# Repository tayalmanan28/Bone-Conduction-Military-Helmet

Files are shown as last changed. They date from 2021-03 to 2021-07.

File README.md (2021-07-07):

# Design of a Bone Conduction Military Helmet

## Course Project for ME 423 [Machine Design]

***

## Overview

Human Auditory nerve, which takes audio signals from cochlea to the brain, is connected to the Organ of Corti in cochlea which is located on the basilar membrane. Therefore the displacement at the basilar membrane directly affects the sound we hear. This basilar membrane can be stimulated in 2 ways:
● Air Conduction: Normal Hearing through eardrum vibrations transmitted via middle ear bones (malleus, incus, and stapes).
● Bone Conduction: Vibrations transmitted through the skull.
The way we hear our own voice even after closing our ears is through bone conduction. Bone conduction also occurs in our Normal Hearing state through the skull but the stimulation on the basilar membrane is extremely low below 100 dB. Above 100 dB we can hear the sound even if we close our ears using ear plugs which is due to bone conduction.

### Working Principle

In this report, bone conduction phenomenon is studied and a bone conduction helmet is designed. The major use of this helmet is for military purposes where the soldier needs to hear the surrounding noises as well as clearly hear the commands from his officer.

### [Project Report](https://github.com/tayalmanan28/Bone-Conduction-Military-Helmet/blob/main/Report.pdf)

### [Presentation](https://github.com/tayalmanan28/Bone-Conduction-Military-Helmet/blob/main/Presentation.pptx)

***

<p align='center'>Created with :heart: by  <a href="https://github.com/tayalmanan28">Manan Tayal</a>, <a> Atharv Kotwal </a>, <a> Milind Chandnani</a> & <a href="https://github.com/AmeyGohil">Amey Gohil</a></p>

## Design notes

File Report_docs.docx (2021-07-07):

Bone Conduction Military Helmet

ME791 Acoustic Devices Autumn 2020

Group:

- Atharv Kotwal (170110068)
- Manan Tayal (170100005)
- Amey Gohil (170100019)
- Milind Chandnani (170110001)

Introduction

Human Auditory nerve, which takes audio signals from cochlea to the brain, is connected to the Organ of Corti in cochlea which is located on the basilar membrane. Therefore the displacement at the basilar membrane directly affects the sound we hear. This basilar membrane can be stimulated in 2 ways:

- Air Conduction: Normal Hearing through eardrum vibrations transmitted via middle ear bones (malleus, incus, and stapes).
- Bone Conduction: is the conduction of sound to the inner ear primarily through the bones of the skull, allowing the hearer to perceive audio content without blocking the ear canal. Bone conduction transmission occurs constantly as sound waves vibrate bone, specifically the bones in the skull, although it is hard for the average individual to distinguish sound being conveyed through the bone as opposed to sound being conveyed through air via the ear canal.

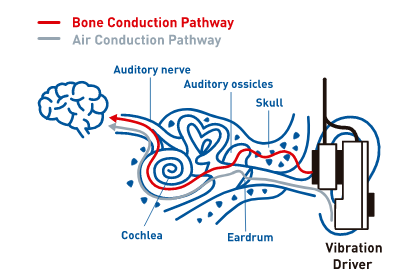
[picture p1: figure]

The way we hear our own voice even after closing our ears is through bone conduction. Bone conduction also occurs in our Normal Hearing state through the skull but the stimulation on the basilar membrane is extremely low below 100 dB. Above 100 dB we can hear the sound even if we close our ears using ear plugs which is due to bone conduction.

Bone conduction: An Overview

Bone conduction is one reason why a person's voice sounds different to them when it is recorded and played back. Because the skull conducts lower frequencies better than air, people perceive their own voices to be lower and fuller than others do, and a recording of one's own voice frequently sounds higher than one expects.

Musicians may use bone conduction using a tuning fork (https://en.wikipedia.org/wiki/Tuning_fork) while tuning stringed instruments. After the fork starts vibrating, placing it in the mouth with the stem between the back teeth ensures that one continues to hear the note via bone conduction, and both hands are free to do the tuning. Ludwig van Beethoven (https://en.wikipedia.org/wiki/Ludwig_van_Beethoven) was famously rumored to be using bone conduction after losing most of his hearing, by placing one end of a rod in his mouth and resting the other end on the rim of his piano.

Comparison of hearing sensitivity through bone conduction and directly through the ear canal can aid audiologists in identifying pathologies of the middle ear (https://en.wikipedia.org/wiki/Middle_ear)—the area between the tympanic membrane (https://en.wikipedia.org/wiki/Eardrum) (ear drum) and the cochlea (inner ear). If hearing is markedly better through bone conduction than through the ear canal (air-bone gap), problems with the ear canal (e.g. ear wax accumulation), the tympanic membrane or ossicles (https://en.wikipedia.org/wiki/Ossicles) can be suspected.

Our Design:

We are planning to design and analyse a military helmet embedded with bone conduction earphones which will be used to transfer the commands directly to the soldier instead of having an earphone which will cover the Soldier’s ear canal and might decrease the spatial awareness which might be critical in a warzone. Various problems will be solved using the design we are proposing and some of them are as below:

- The Soldiers in the war need to keep a walky talky in their hands in order to communicate with the control room and with each other. Also, if they wear a headphone over their ears they can only focus on talking and may miss the noise of some bullet/ bomb blast.
- So they need to talk to each other while knowing the war environment. And therefore they might want to use a bone conduction headphone with a mic to hear the sounds from the environment and at the same time talk to each other.
- Moreover since above 100 dB we can hear the sound even if we close our ears using ear plugs which is due to bone conduction, we can analyse the insulation through bone conduction.

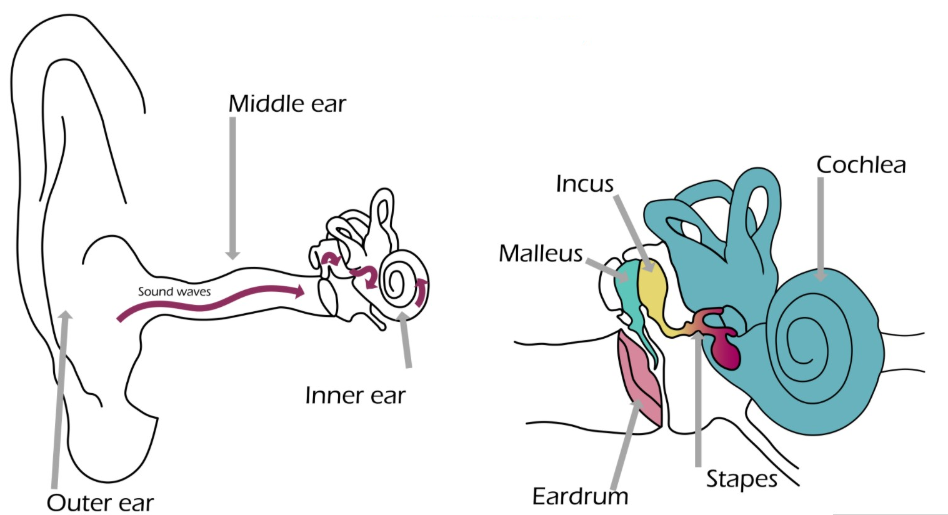
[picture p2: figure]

Working Principles

In this report, bone conduction phenomenon is studied and a bone conduction helmet is designed. The major use of this helmet is for military purposes where the soldier needs to hear the surrounding noises as well as clearly hear the commands from his officer.

The idea is to give commands using the bone conduction signal whereas the outside noises can be heard using normal air conduction hearing.

Modelling

Bone conduction happens through the skull, hence, ideally simulations should be performed on the whole skull. But to ease the complexity of the model, the skull was modelled as a sphere and some features like cochlear bones, ear canal and a flat surface to give vibrations were added. In the approximated skull 2 large holes are given to approximate many small openings in the skull. The images below show the approximated mesh as well as actual skull.

Cochlear Bones are highlighted in both. At the end of these bones a basilar membrane is presented.

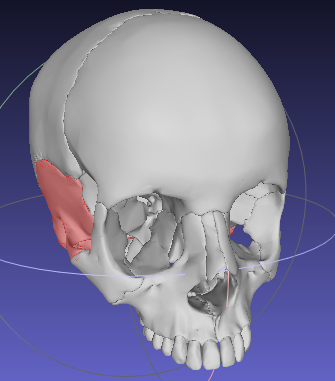
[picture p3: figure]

Actual Skull :

Material Properties of Bone:

Young’s Modulus E | 7300 MPa
Density | 870 kg/m³
Poisson Ratio | 0.3

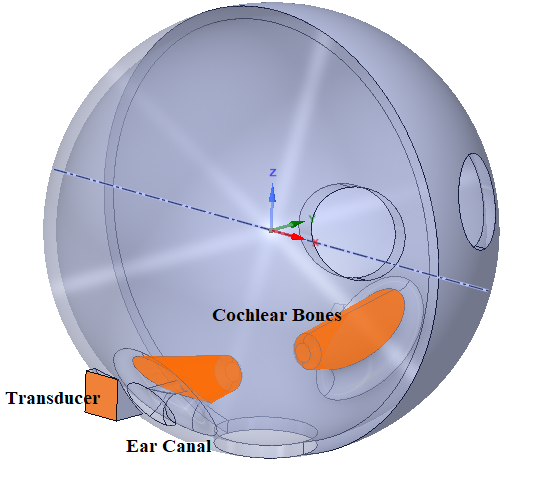
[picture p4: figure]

Approximated Model: Same material

Skull Thickness | 7.5 mm
Skull Diameter | 25 cm
Cochlear bone length | 7 cm
Cochlear bone diameter | 3 cm
Ear Canal Length | 3 cm
Ear Canal diameter | 8 mm
Transducer Area | 2.5 * 2.5 cm²

Model Validation

Model is validated by giving a point load of 1 N at one end (where the transducer is highlighted in Figure above). The mechanical impedance at the input was compared with the literature.

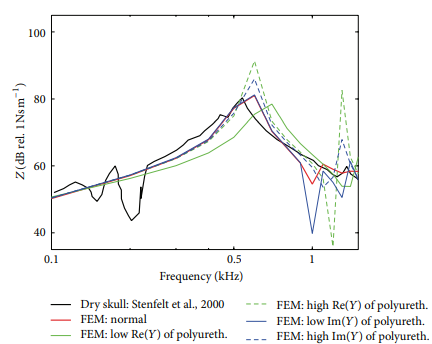
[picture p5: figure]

Literature:

Frequency Range: 100 - 1500 Hz

Model:

Frequency Range: 100 - 5000 Hz

- Trend is similar as given in literature.
- The peak occurs at 800 Hz compared to 600 Hz in literature.
- Mechanical Impedance of the model is higher than the actual skull given in literature because a uniform thickness sphere is considered everywhere which increases the stiffness whereas the actual skull has many openings and variation in thickness.

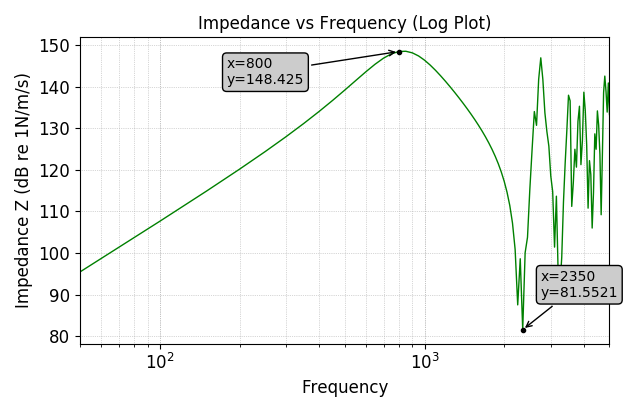
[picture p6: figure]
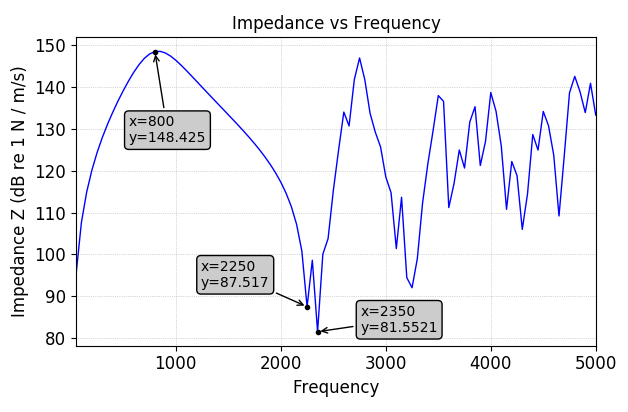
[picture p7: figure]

Frequency Range Selection

Now, a dynamic load is given over the whole area of transducer (2.5cm * 2.5cm) and Frequency Response is obtained for displacement at the end of cochlear bone.

Frequency Range: 50 - 5000 Hz

Load: 0.01 N

Transducer Area: 2.5 cm * 2.5 cm = 6.25 * 10 ⁻ ⁴ cm²

Pressure on Transducer: 16 Pa

Boundary Conditions:

- Fixed Support where skull connects the neck
- Specific Force on Transducer Area on both sides

Probe: Measure displacement at the end of cochlear bone which connects to basilar membrane

Software: Ansys Harmonic Response

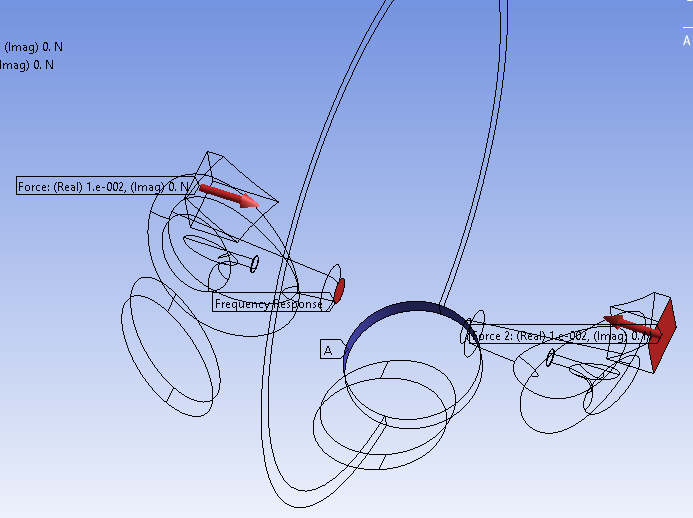
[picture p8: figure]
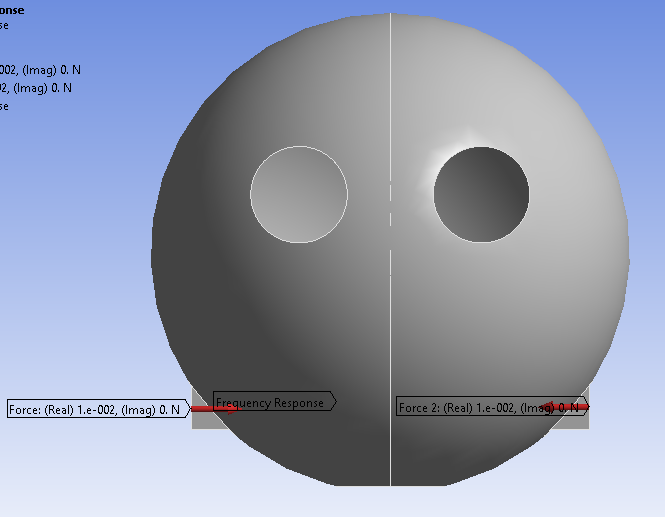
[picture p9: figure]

Results

Mechanical Impedance vs Frequency:

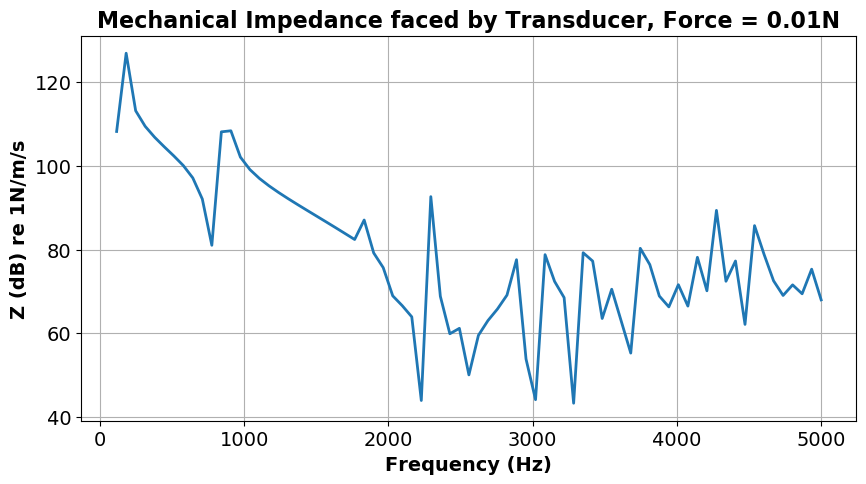
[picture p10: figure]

Frequency Response of Displacement at Basilar membrane:

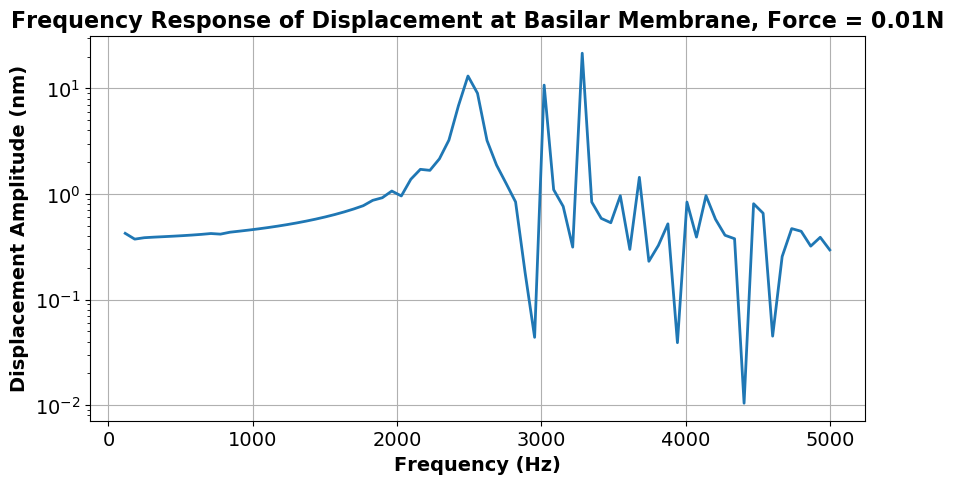
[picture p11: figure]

- The low frequency region ( <1500 Hz ) is not possible because of transducer limitations. Transducers of small sizes work best for higher frequencies.
- There is a peak at 2500 Hz where displacement is ~ 10 nm which is high for the basilar membrane. Also between 2300 - 3500 Hz, the region is highly non-linear with many peaks and troughs which is not good.
- Frequencies after 4000 Hz have smaller displacements.
- The best frequency range for our purpose is therefore 1800 - 2200 Hz i.e. we can tune the transducer around 2000 Hz Frequency.

Clamping Force Selection

The same model above is iterated a few times to get the best possible displacements at the basilar membrane.

Average displacement in frequency range 1800 - 2200 Hz:

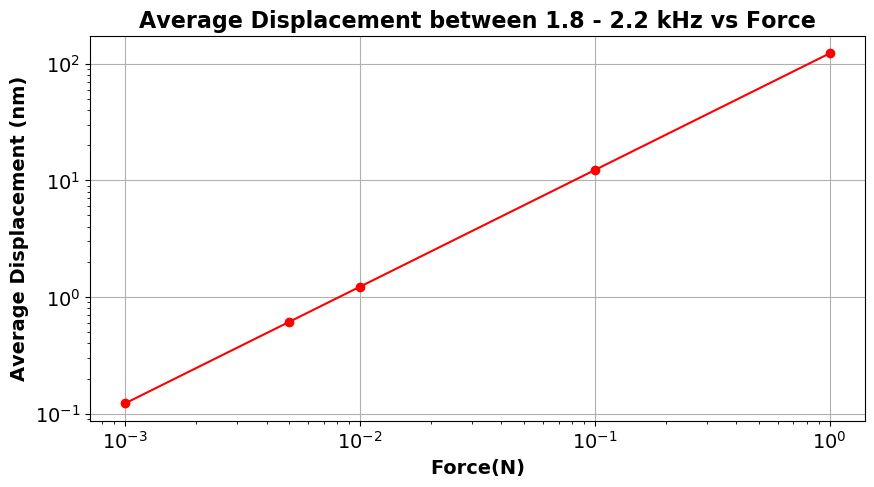
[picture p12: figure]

- Plot is fairly linear. Best Fit Equation:

log(disp in nm) = log(Force) + 2.089

- Displacement at the basilar membrane should be around 0.6 nm.
- Hence, the force amplitude to be applied on the skull should be ~ 0.005 N.
- Using the above equation force can be calculated for any displacement. Displacement at the basilar membrane for a particular frequency is directly proportional to the loudness of sound we hear.

Force amplitude on skull = 0.005 N

Pressure Amplitude ∆p = Force / Area = 0.005 / (2.5 * 2.5 cm² ) = 8 Pa

When a unit volt is passed through piezoelectric material it expands by ∆l

Therefore, εpiezo=∆l/l = d*E =d*V/l (where d is piezoelectric coefficient)

=2*10⁻¹² * (1/0.5*10⁻³)

=4*10⁻⁹

If we consider the skull bone to be stiff enough,

∆p/p =εpiezo / ε

= 4*10⁻⁹/1.6*10⁻⁶ (Allowable strain corresponding to the bearable stress)

=0.0025

In our case ∆p = 8 Pa

therefore, p = 8/0.0025Pa = 3200 Pa

Clamping Force = p * A = 3200 * (2.5 * 2.5 cm²) = 2 N.

Clamping Force can be slightly varied as per user requirement using the screw. Force on skull (= 0.0025 * Clamping Force ), which is a function of Clamping Force, governs the displacement of the membrane.

Effect of External Sound on Displacement at Cochlear End and Acoustic Insulation

A simple model of cochlear bone and external environment (Air domain) is created in Actran and displacements are calculated at cochlear end.

Air Domain | 30 cm * 30 cm * 30 cm
Cochlear bone length | 7 cm
Cochlear bone diameter | 3 cm

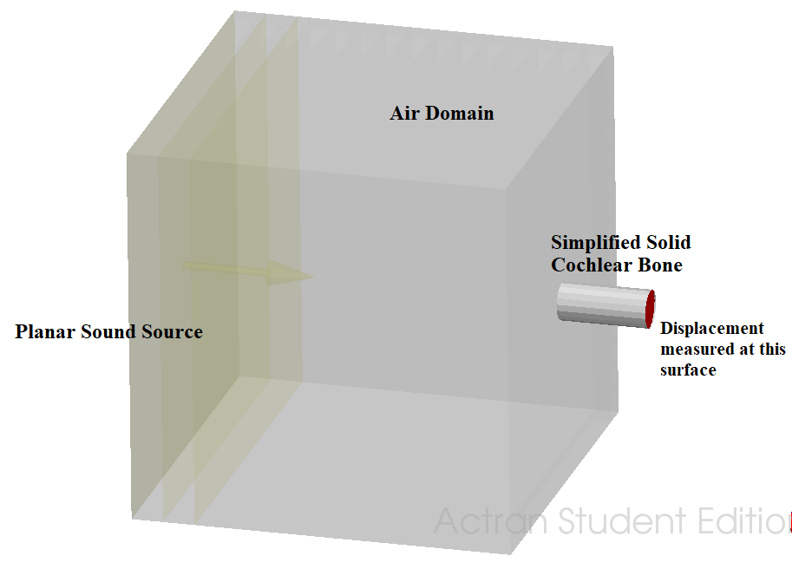
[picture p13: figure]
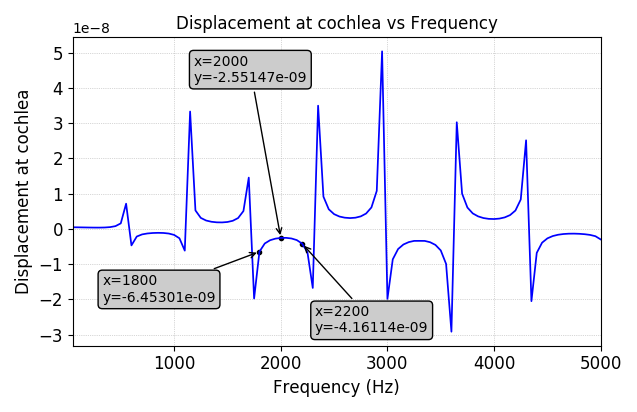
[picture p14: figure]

5 iterations were done with different pressure amplitudes.

Following graph shows displacement at cochlea for 100 Pa pressure Amplitude.

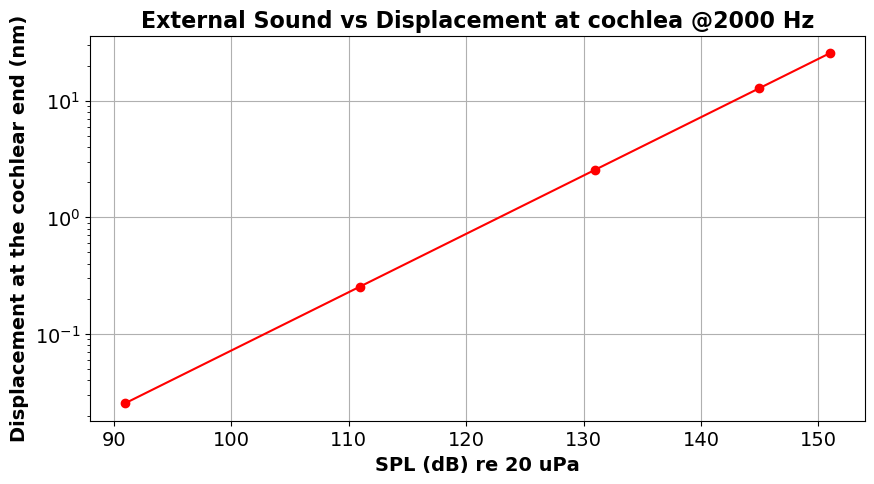
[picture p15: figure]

For 2000 Hz Frequency displacements are plotted against SPL (function of Pressure Amplitudes.)

- Plot is fairly linear.
- This clearly shows that above 100 dB, there is reasonable displacement due to bone conduction also on the basilar membrane of cochlea.
- This means that in a harsh acoustic environment (like navy aircraft carriers or sound of guns which goes upto 140 dB) with high noise levels even if the person wears ear plugs, he may end up damaging his basilar membrane because sound vibrations will travel through bone conduction.

Hence, a helmet is required which will attenuate these vibrations from entering the skull. Special materials like foam are inserted in the helmet for these purposes.

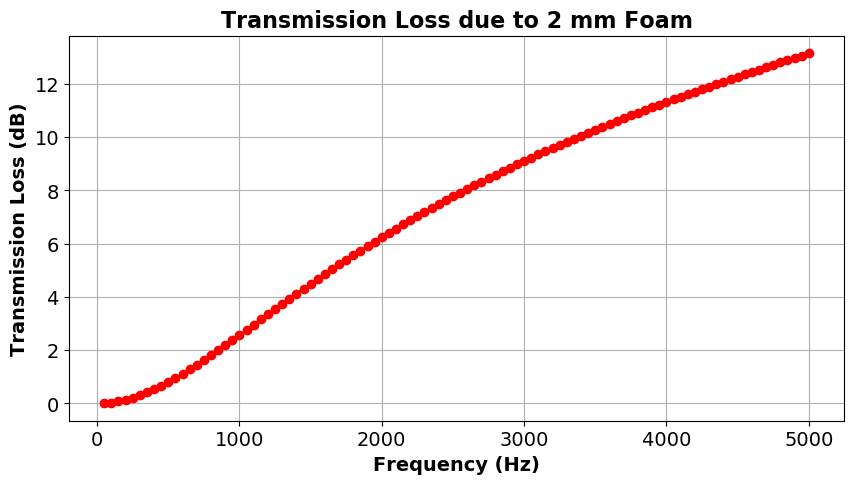
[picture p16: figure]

The bullets and bomb blasts generally create a noise at 1000Hz of frequency.

Sound to attenuate = 40 dB

Therefore, we need at least (40 / 2.5)*2mm = 32mm of foam to attenuate this noise.

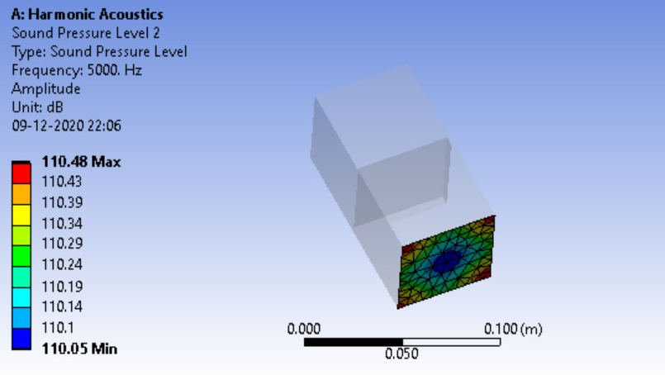
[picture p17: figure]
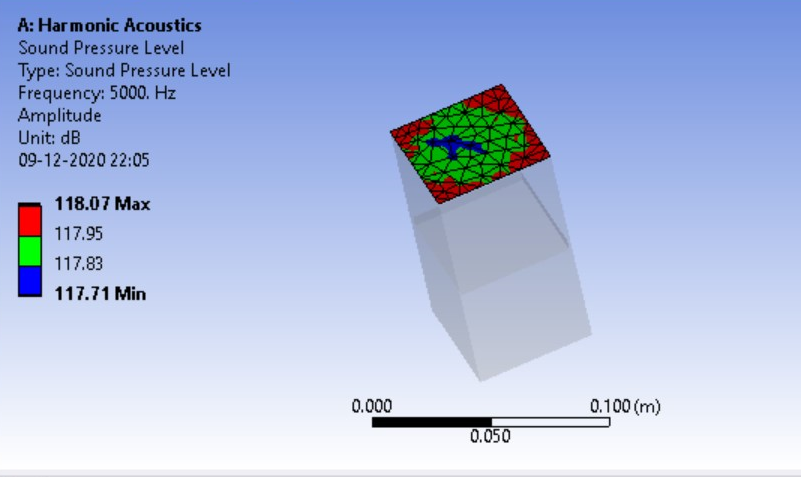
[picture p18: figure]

Electronics Circuit

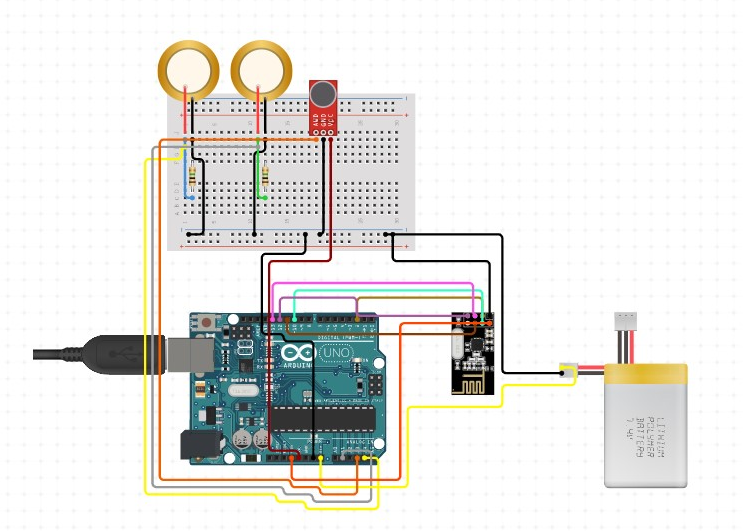
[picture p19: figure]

The electronics part contains Arduino (microcontroller), NRF24L01 - 2.4G Wireless Transceiver Module to receive and transmit the signals back and forth to the soldier, Piezo Transducer to conduct the signals from circuit to the cochlea via bone, Lithium Polymer Battery to power up the circuit and the microphone to communicate.

Material Analysis

Firstly we will analyse the impact analysis (if the thickness of a certain material can prevent the bullet from piercing the material).

Considering the following conditions we obtain the table below:

Bullet: Lead 20 mm Factor of Safety = 2 Velocity of the Bullet: 500 m/s

Plate Material | Thickness | Remarks | Thickness with FOS | Mass (kg)
Steel | 0.5 mm | Failed | 1mm | 0.8
Kevlar | 0.5 mm | Failed | 1mm | 0.144
UHMWP | 0.5 mm | Failed | 1mm | 0.097
Steel | 3 mm | Passed | 6mm | 4.8
Kevlar | 3 mm | Passed | 6mm | 0.864
UHMWP | 3 mm | Failed | 6mm | 0.582
UHMWP | 4 mm | Failed | 8mm | 0.776
UHMWP | 8 mm | Passed | 16mm | 1.552

Following are the gifs of the impact on the flat plate

Kevlar 3mm UHMWP 3mm

UHMWP 4mm UHMWP 8mm

Manufacturing drawings

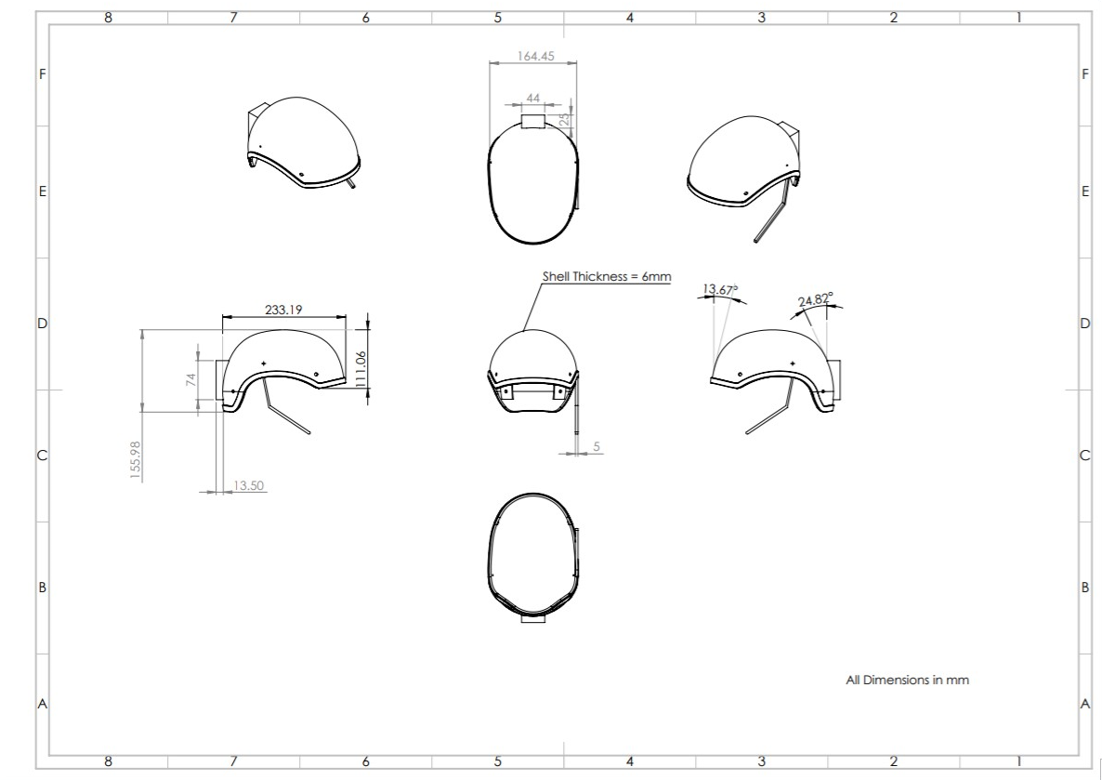
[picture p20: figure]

CAD Models

Helmet

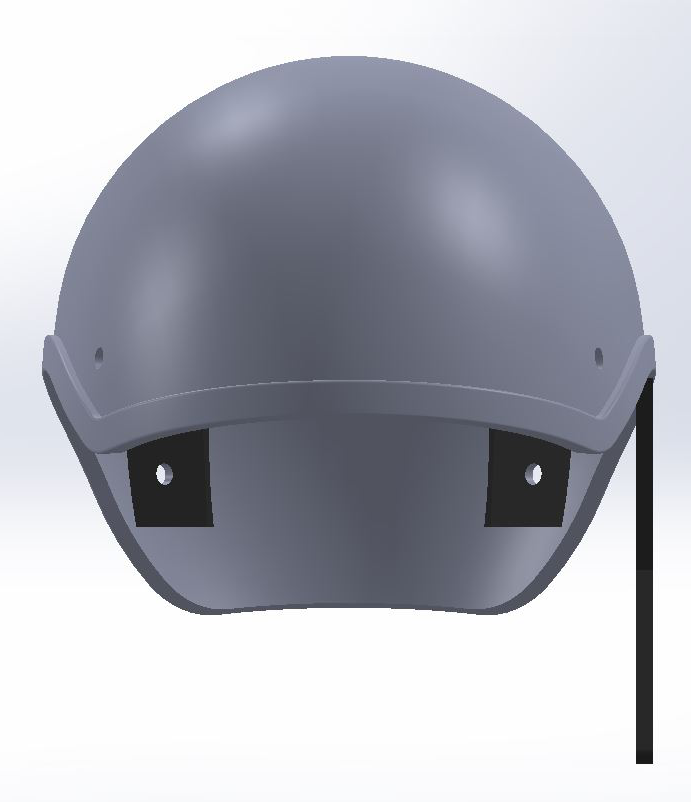
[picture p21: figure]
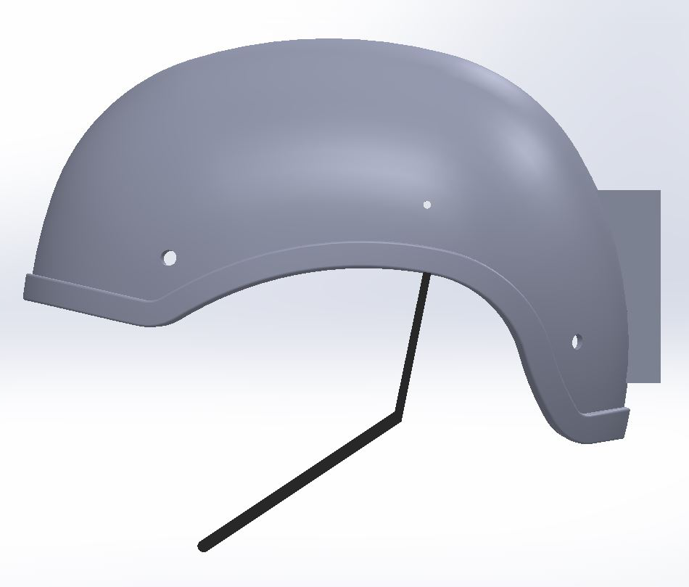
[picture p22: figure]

A basic helmet model is made using SolidWorks. It has a box compartment to store the electrical circuit on the back side. For placing the transducer, there are two slots on the inner surface at the back of the helmet. A metal strip is added on the side to account for the mike for communication purposes.

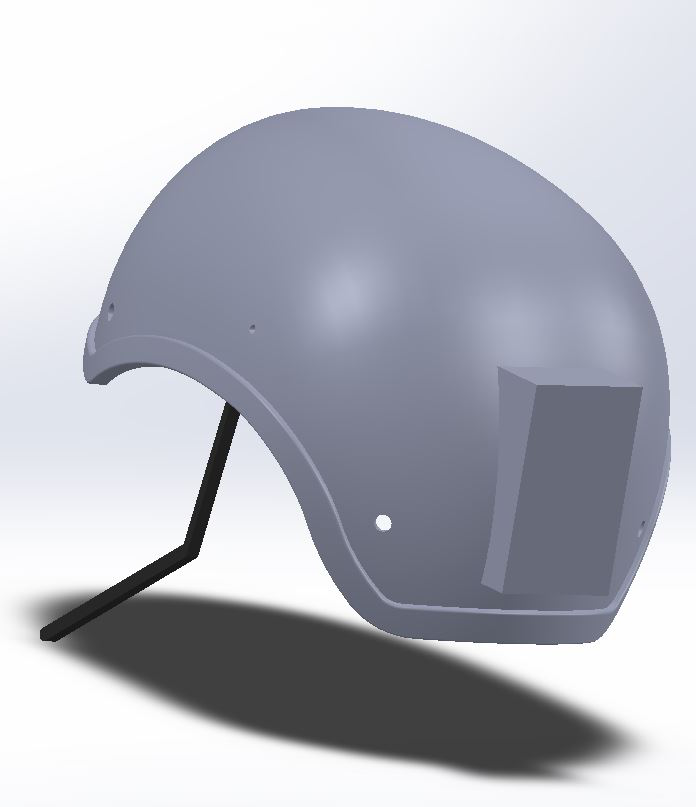
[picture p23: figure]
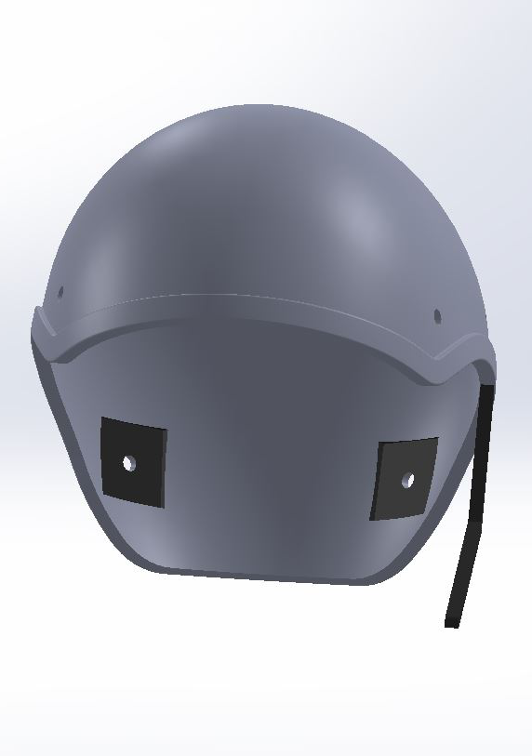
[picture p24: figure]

Spring Plunger

A spring plunger is also added to make fine adjustments

For Fine tuning of contact force mentioned above, We want 0.02N change in one pitch (pitch 1.25mm)

Stiffness of spring is 0.02N/1.25mm = 16N/m.

Bill of the components

Name of component | Quantity | Price (in INR)
Arduino | 1 | 500
NRF24L01 - 2.4G Wireless Transceiver Module | 1 | 100
Piezo Transducer | 2 | 60
1.0M Ohm Resistor | 2 | 2
Lithium Polymer Battery - 7.4v | 1 | 1000
Microphone | 1 | 250
Wires | | 50
Perforated Board | 2 | 80
Kevlar | 1kg | 600
Foam | | 1000
Spring Plunger | 2 | 200
Miscellaneous | | 500
Total | | 4042

Final Design Specifications

Helmet Thickness - 6mm Helmet Mass Volume - 582.93cm³

Material - Kevlar Mass of Helmet - 864 gm

Spring Plunger pitch - 1.25mm

Stiffness = 16N/m

Transducer Area - 2.5 cm * 2.5 cm³

Clamping Force - 2N

Frequency Range - 1800 - 2200 Hz

Summary and Highlights of the project

Final Product is a Helmet for Military Purposes with these features:

- Bone Conduction transmission of sound for clear hearing of commands
- Acoustically Insulating Foam for high noise levels.
- Other features of helmet like bullet proofing etc.

The main aim of the project was to incorporate bone conduction transmission in helmets and to prevent the external large sounds to enter the head and thereby the cochlea along with the traditional use to protect the head from bullets.

Contribution from each member

Atharv Kotwal | 25% | Acoustic Analysis: Frequency and Clamping Force Selection
Manan Tayal | 25% | Electronic Circuit and Acoustic Insulation
Amey Gohil | 25% | CAD Modelling
Milind Chandnani | 25% | Material Selection using Ansys Impact Analysis and Simulations

Link of all the Ansys, Actran & CAD Models along with a few videos is here (https://drive.google.com/drive/folders/1KnRmxevO2PZcEWRhP4DjEP5oWg9iEjO7?usp=sharing)

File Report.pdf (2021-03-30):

/

## Bone Conduction Military Helmet

### ME423 Machine Design Autumn 2020 Group 8

- Atharv Kotwal (170110068)
- Manan Tayal (170100005)
- Amey Gohil (170100019)
- Milind Chandnani (170110001)
- Bavish K (170040106)

Human Auditory nerve, which takes audio signals from cochlea to the brain, is connected to the Organ of Corti in cochlea which is located on the basilar membrane. Therefore the displacement at the basilar membrane directly affects the sound we hear. This basilar membrane can be stimulated in 2 ways:
- Air Conduction: Normal Hearing through eardrum vibrations transmitted via middle ear bones (malleus, incus, and stapes).
- Bone Conduction: Vibrations transmitted through the skull.
The way we hear our own voice even after closing our ears is through bone conduction. Bone conduction also occurs in our Normal Hearing state through the skull but the stimulation on the basilar membrane is extremely low below 100 dB. Above 100 dB we can hear the sound even if we close our ears using ear plugs which is due to bone conduction.

Need
- The Soldiers in the war need to keep a walky talky in their hands in order to communicate with the control room and with each other. Also, if they wear a headphone over their ears they can only focus on talking and may miss the noise of some bullet/ bomb blast.
- So they need to talk to each other while knowing the war environment. And
| therefore they might want to use a bone conduction headphone with a mic to
| hear the sounds from the environment and at the same time talk to each other.
- Moreover since above 100 dB we can hear the sound even if we close our ears using ear plugs which is due to bone conduction, we can analyse the insulation through bone conduction.

Working Principles
In this report, bone
conduction phenomenon is
studied | and | a | bone
conduction | helmet | is
designed. The major use of this helmet is for military purposes where the soldier
needs | to | hear | the
surrounding noises as well
as | clearly | hear | the
commands from his officer.


The idea is to give commands using the bone conduction signal whereas the outside noises can be heard using normal air conduction hearing.

### Modelling

Bone conduction happens through the skull, hence, ideally simulations should be performed on the whole skull. But to ease the complexity of the model, the skull was modelled as a sphere and some features like cochlear bones, ear canal and a flat surface to give vibrations were added. In the approximated skull 2 large holes are given to approximate many small openings in the skull. The images below show the approximated mesh as well as actual skull.
Cochlear Bones are highlighted in both. At the end of these bones a basilar membrane is presented.

Actual Skull :

Material Properties of Bone:


Approximated Model: Same material

Young’s Modulus E | 7300 MPa
Density | 870 kg/m³
Poisson Ratio | 0.3
Skull Thickness | 7.5 mm
Skull Diameter | 25 cm
Cochlear bone length | 7 cm
Cochlear bone diameter | 4 cm
Ear Canal Length | 3 cm
Ear Canal diameter | 8 mm
Transducer Area | 2.5 * 2.5 cm²

### Model Validation


Model is validated by giving a point load of 1 N at one end (where the transducer is highlighted in Figure above). The mechanical impedance at the input was compared with the literature.

Literature:
Frequency Range: 100 - 1500 Hz

Model:
Frequency Range: 100 - 5000 Hz
- Trend is similar as given in literature.
- The peak occurs at 800 Hz
compared to 600 Hz in
literature.
- Mechanical Impedance of the model is higher than the actual skull given in literature because a uniform thickness sphere is considered everywhere which increases the stiffness whereas the actual skull has many openings and variation in thickness.

### Frequency Range Selection

Now, a dynamic load is given over the whole area of transducer (2.5cm * 2.5cm) and Frequency Response is obtained for displacement at the end of cochlear bone.

Frequency Range: 50 - 5000 Hz
Load: 0.01 N
Transducer Area: 2.5 cm * 2.5 cm = 6.25 * 10
- 4 cm²
Pressure on Transducer: 16 Pa

Boundary Conditions:
- Fixed Support where skull connects the neck
- Specific Force on Transducer Area on both sides

Probe: Measure displacement at the end of cochlear bone which connects to basilar membrane
Software: Ansys Harmonic Response


Results
Mechanical Impedance vs Frequency:


Frequency Response of Displacement at Basilar membrane:


- The low frequency region ( <1500 Hz ) is not possible because of transducer limitations. Transducers of small sizes work best for higher frequencies.
- There is a peak at 2500 Hz where displacement is ~ 10 nm which is high for the basilar membrane. Also between 2300 - 3500 Hz, the region is highly non-linear with many peaks and troughs which is not good.
- Frequencies after 4000 Hz have smaller displacements.
- The best frequency range for our purpose is therefore 1800 - 2200 Hz i.e. we can tune the transducer around 2000 Hz Frequency.

### Clamping Force Selection

The same model above is iterated a few times to get the best possible displacements at the basilar membrane.
Average displacement in frequency range 1800 - 2200 Hz:


- Plot is fairly linear. Best Fit Equation:
log(disp in nm) = log(Force) + 2.089
- Displacement at the basilar membrane should be around 0.6 nm.
- Hence, the force amplitude to be applied on the skull should be ~ 0.005 N.
- Using the above equation force can be calculated for any displacement. Displacement at the basilar membrane for a particular frequency is directly proportional to the loudness of sound we hear.

Force amplitude on skull = 0.005 N
Pressure Amplitude ∆p = Force / Area = 0.005 / (2.5 * 2.5 cm²
) = 8 Pa

When a unit volt is passed
through piezoelectric material it
expands by ∆l
Therefore, εpiezo=∆l/l
= d*E =d*V/l | (where
d is piezoelectric coefficient)


=2*10 | -12 * (1/0.5*10

-3
)
=4*10

-9

If we consider the skull bone to be stiff enough, ∆p/p =εpiezo

/ ε
= 4*10

-9
/1.6*10

-6
(Allowable strain corresponding to the bearable stress) =0.0025
In our case ∆p = 8 Pa
therefore, p = 8/0.0025Pa = 3200 Pa
Clamping Force = p * A = 3200 * (2.5 * 2.5 cm²
) = 2 N.

Clamping Force can be slightly varied as per user requirement using the screw. Force on skull (= 0.0025 * Clamping Force ), which is a function of Clamping Force, governs the displacement of the membrane.

Acoustic Insulation in Helmet:
Using the force applied through the transducer, equivalent Sound Pressure Level can be calculated using the following:
SPL(dB) = 20 * log ( P / Pref ) , where, Pref = 20 * 10

-6 Pa
P = F / A , A = 2.5 * 2.5 cm²


- This plot shows that if the external sound is above 100 dB, then it can be perceived by cochlea through bone conduction.
- This means that in a harsh acoustic environment (like navy aircraft carriers or sound of guns which goes upto 140 dB) with high noise levels even if the person wears ear plugs, he may end up damaging his basilar membrane because sound vibrations will travel through bone conduction.

- Hence, a helmet is required which will attenuate these vibrations from entering the skull. Special materials like foam are inserted in the helmet for these purposes.


The bullets and bomb blasts generally create a noise at 1000Hz of frequency. Sound to attenuate = 40 dB
Therefore, we need at least (40 / 2.5)*2mm = 32mm of foam to attenuate this noise.


Electronics Circuit


The electronics part contains Arduino (microcontroller), NRF24L01 - 2.4G Wireless Transceiver Module to receive and transmit the signals back and forth to the soldier, Piezo Transducer to conduct the signals from circuit to the cochlea via bone, Lithium Polymer Battery to power up the circuit and the microphone to communicate.

Material Analysis
Firstly we will analyse the impact analysis (if the thickness of a certain material can prevent the bullet from piercing the material).
Considering the following conditions we obtain the table below:
Bullet: Lead 20 mm | Factor of Safety = 2 | Velocity of the Bullet: 500 m/s

Following are the gifs of the impact on the flat plate


Kevlar 3mm | UHMWP 3mm


UHMWP 4mm | UHMWP 8mm
Plate Material | Thickness | Remarks | Thickness with FOS | Mass (kg)
Steel | 0.5 mm | Failed | 1mm | 0.8
Kevlar | 0.5 mm | Failed | 1mm | 0.144
UHMWP | 0.5 mm | Failed | 1mm | 0.097
Steel | 3 mm | Passed | 6mm | 4.8
Kevlar | 3 mm | Passed | 6mm | 0.864
UHMWP | 3 mm | Failed | 6mm | 0.582
UHMWP | 4 mm | Failed | 8mm | 0.776
UHMWP | 8 mm | Passed | 16mm | 1.552


Next we need to analyse the impact energy of the cases in which the bullet is not penetrating:

Kevlar 3mm Plate

Max impact (internal) energy is around 3900J
Therefore, impact strength is impact (internal) energy/ thickness= 3900/3 J/mm = 1.3 MJ/m
UHMWP 8mm Plate

Max impact (internal) energy is around 4100J
Therefore, impact strength is impact (internal) energy/ thickness = 4100/8 J/mm = 0.512 MJ/m


Manufacturing drawings

CAD Models

Helmet

A basic helmet model is made using SolidWorks. It has a box compartment to store the electrical circuit on the back side. For placing the transducer, there are two slots on the inner surface at the back of the helmet. A metal strip is added on the side to account for the mike for communication purposes.

Spring Plunger

A spring plunger is also added to make fine adjustments
For Fine tuning of contact force mentioned above, We want 0.02N change in one pitch (pitch 1.25mm)
Stiffness of spring is 0.02N/1.25mm = 16N/m.

Bill of the components


Name of component | Quantity | Price (in INR)
Arduino | 1 | 500
NRF24L01 - 2.4G Wireless Transceiver Module | 1 | 100
Piezo Transducer | 2 | 60
1.0M Ohm Resistor | 2 | 2
Lithium Polymer Battery - 7.4v | 1 | 1000
Microphone | 1 | 250
Wires | | 50
Perforated Board | 2 | 80
Kevlar | 1kg | 600
Foam | | 1000
Spring Plunger | 2 | 200
Miscellaneous | | 500
Total | | 4042

Final Design Specifications
Helmet Thickness - 6mm | Helmet Mass Volume - 582.93cm³
Material - Kevlar | Mass of Helmet - 864 gm
Spring Plunger pitch - 1.25mm
Stiffness = 16N/m
Transducer Area - 2.5 cm * 2.5 cm³
Clamping Force - 2N
Frequency Range - 1800 - 2200 Hz

### Summary and Highlights of the project

Final Product is a Helmet for Military Purposes with these features:

- Bone Conduction transmission of sound for clear hearing of commands
- Acoustically Insulating Foam for high noise levels.
- Other features of helmet like bullet proofing etc.

The main aim of the project was to incorporate bone conduction transmission in helmets and to prevent the external large sounds to enter the head and thereby the cochlea along with the traditional use to protect the head from bullets.

Contribution from each member

Atharv Kotwal | 20% | Acoustic Analysis: Frequency and Clamping Force Selection
Manan Tayal | 20% | Electronic Circuit and Acoustic Insulation
Amey Gohil | 20% | CAD Modelling
Milind Chandnani | 20% | Material Selection using Ansys Impact Analysis and Simulations
Bavish K | 20% | CAD Modelling , Acoustic Model Approximation

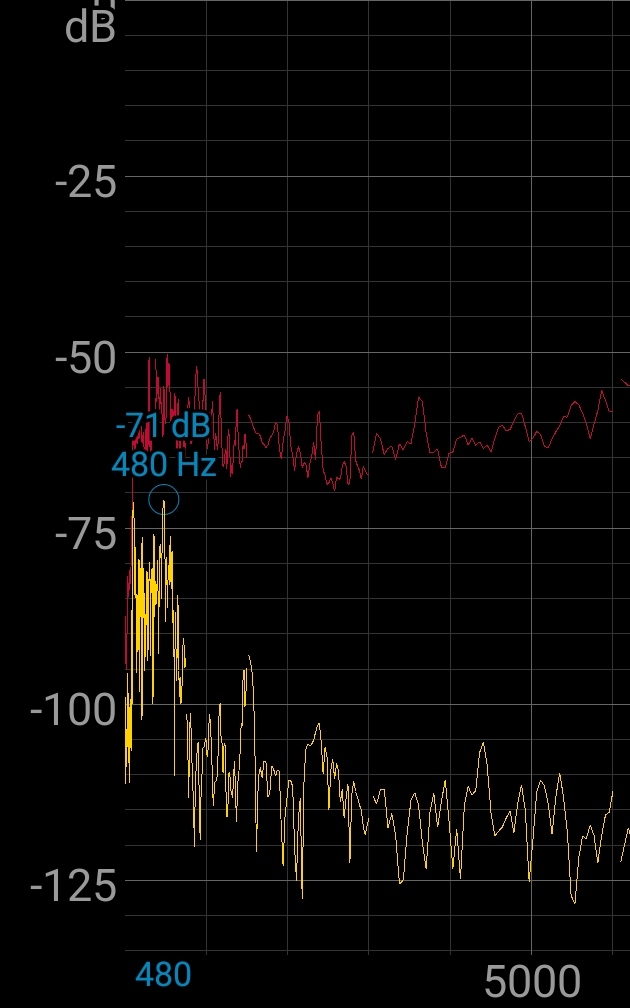
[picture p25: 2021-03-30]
Electrical Simulation/Piezo_off.jpeg

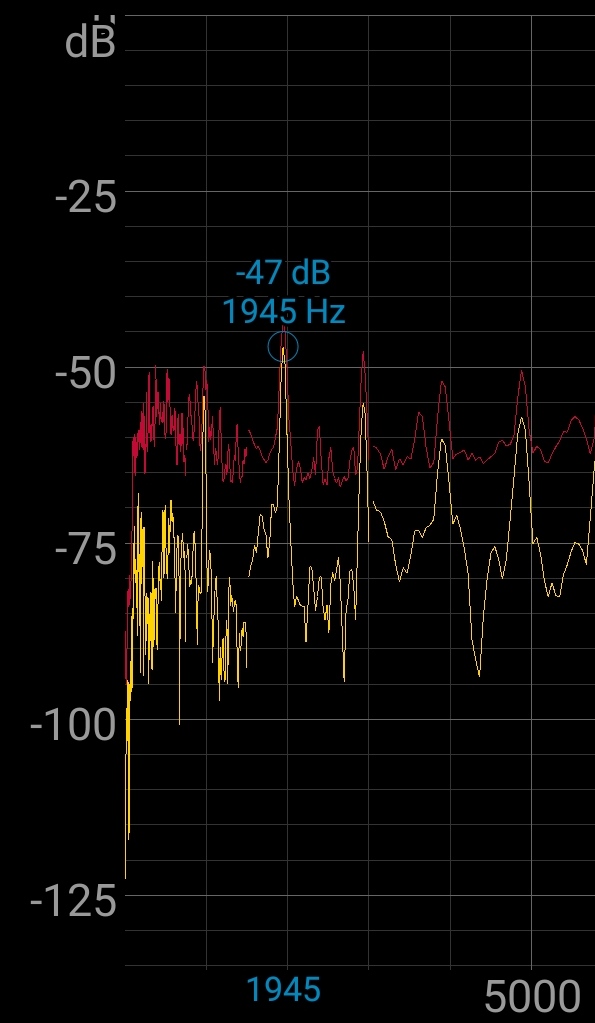
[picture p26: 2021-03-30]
Electrical Simulation/Piezo_on.jpeg

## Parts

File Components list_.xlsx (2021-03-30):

Name of component | Quantity | Price
Arduino Uno | 1 | 500
NRF24L01 - 2.4G Wireless Transceiver Module | 1 | 100
Piezo Transducer | 2 | 60
1.0M Ohm Resistor | 2 | 2
Lithium Polymer Battery - 7.4v | 1 | 1000
Microphone | 1 | 250
Wires |  | 50
Perforated Board | 2 | 80
Kevlar
Foam |  | 1000
Spring Plunger | 2 | 200
Total |  | 3242

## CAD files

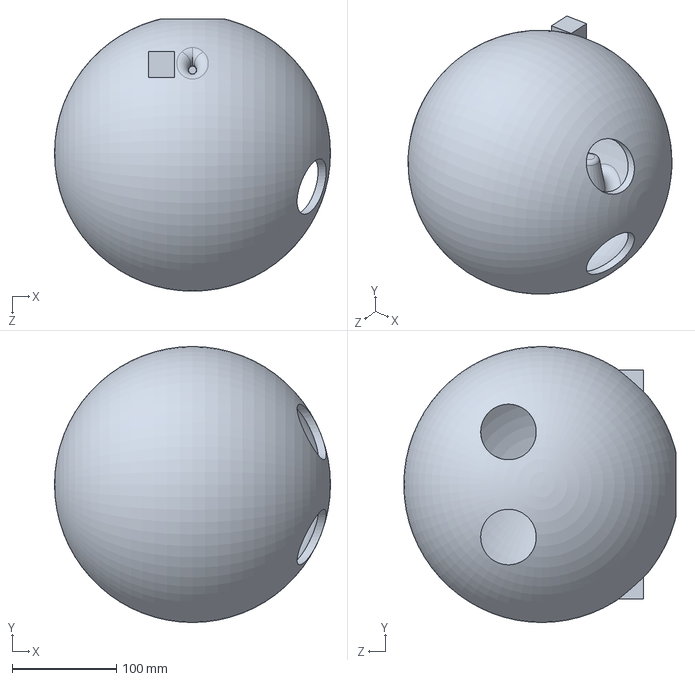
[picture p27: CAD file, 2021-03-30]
Acoustics Analysis/Solid Model/skullapprox.SLDPRT
265.0 x 265.0 x 261.6 mm

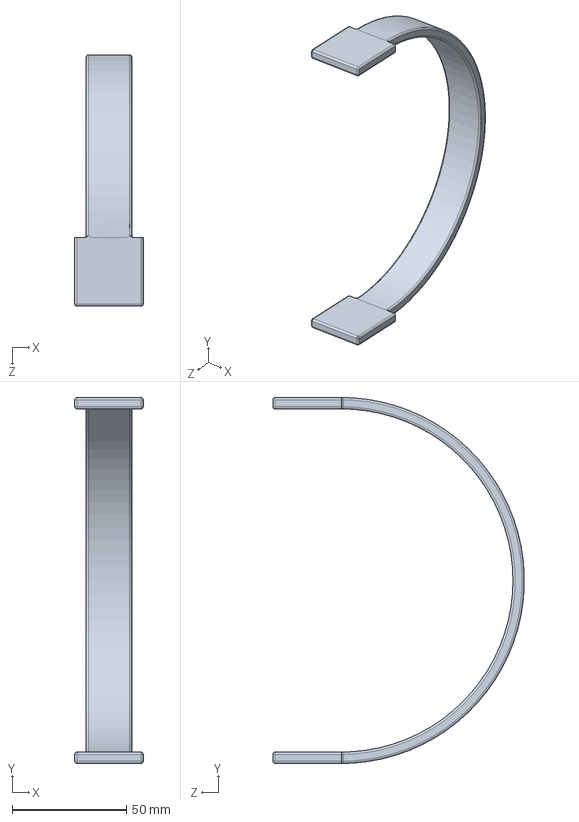
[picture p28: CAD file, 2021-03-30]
CAD Models/Cad Model.SLDPRT
30.0 x 160.0 x 109.9 mm

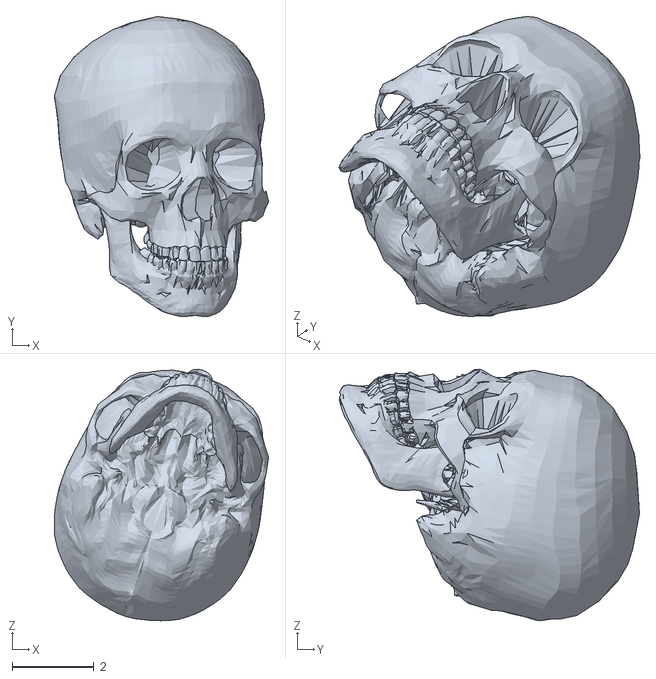
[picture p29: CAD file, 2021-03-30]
Acoustics Analysis/Solid Model/skull.stl
5.23 x 7.32 x 6.14

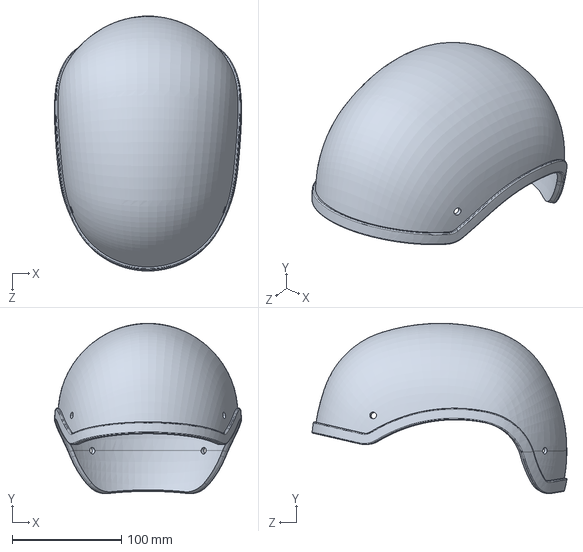
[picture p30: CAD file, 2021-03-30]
CAD Models/Helmet-.SLDPRT
171.6 x 156.1 x 233.7 mm

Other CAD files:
Acoustics Analysis/Solid Model/skullapprox.IGS
